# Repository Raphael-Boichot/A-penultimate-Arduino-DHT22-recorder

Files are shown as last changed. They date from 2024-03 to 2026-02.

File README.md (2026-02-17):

# Yet another Arduino DHT22 recorder on SD card (but with RTC)

## Why ?
Because I was not satisfied by other similar projects for my particular need: recording temperature and humidity every minute for very long periods of time (typically weeks) in remote parts of buildings. This device is so intended to be lost somewhere and survive power failures without much consequences on data stored. I've used it for recording two consecutive weeks of temperature and humidity without touching it, it worked. Current draw is very minimal and it can run for days on a powerbank. The whole price with 5 custom PCBs included should stay below 20€ shipped to your door direct through the silky road.

## How to use it ?
- Install the [Arduino IDE](https://www.arduino.cc/en/software), the [Adafruit sensor library](https://github.com/adafruit/Adafruit_Sensor), the [Adafruit DHT library](https://github.com/adafruit/DHT-sensor-library), the [U8g2 library for monochrome displays](https://github.com/olikraus/u8g2) and the [Adafruit RTClib library](https://github.com/adafruit/RTClib) from the IDE library manager;
- Flash the [DHT22_SD_Set_RTC.ino](Codes/DHT22_SD_Set_RTC/DHT22_SD_Set_RTC.ino) code to the device, it will set the date/time of the RTC module from the computer. The green LED stays ON if everything is OK. The serial must be set at 115200 bauds to check the output from Arduino IDE;
- Then flash the [DHT22_SD_Recorder.ino](Codes/DHT22_SD_Recorder/DHT22_SD_Recorder.ino) code. It immediately starts recording. You can follow what happens on the Arduino IDE serial or use [Read_from_Serial.m](Matlab_Stuff/Read_from_Serial.m) to plot temperature and humidity in live from Matlab;
- As long as green LED flashes only, everything is OK with the 3 modules. Any failure of one of them and the red LED flashes instead;
- SD card can be removed at any time to plot data, the device does not care, no need to power cycle it to plug the SD card back;
- When finished, data can be plotted from the SD card with [Read_from_txt_file.m](Matlab_Stuff/Read_from_txt_file.m), the Matlab code provided, but any other code would work as the data format is very simple;

Codes provided to extract data may be easily adapted to GNU Octave or Scilab.
 
## Parts needed
- An [Arduino Uno](https://fr.aliexpress.com/item/1005006088733150.html), the cheaper the better;
- A [generic microSD shield](https://fr.aliexpress.com/item/1005006059963950.html) or any other size if you do not use the custom PCB provided;
- A [DHT22 module with everything integrated](https://fr.aliexpress.com/item/1005005996195284.html). The red AM2302 stuff is the one I used;
- A [DS3231 RTC module](https://fr.aliexpress.com/item/1005005973972157.html). The extra chip on this board is just an independant 4kB flash chip that is not in use in this application (no idea what's the purpose in fact). It is recommended to [remove the resistor like in this image](Pictures/Resistor_to_remove.png) used for the janky charging circuit as the backup battery is not meant to be charged in fact;
- Some [male pin headers](https://fr.aliexpress.com/item/1005006104110168.html). The clearance with the Arduino Uno shield is tight, but triming the pins below the PCB is enough to go with regular 11 mm pin headers for the short board. The long one requires 15 mm pins headers at least;
- If you want to make the board entirely dismountable, use some [female regular pin headers](https://fr.aliexpress.com/item/1005006468451122.html) to connect the SD, RTC and DHT22 modules instead of soldering them directly;
- A [Custom PCB](https://github.com/Raphael-Boichot/A-penultimate-Arduino-DHT22-recorder/tree/main/PCB) if you want to stay on the neat side. Order at [JLCPCB](https://jlcpcb.com/), it's cheap and custom clean for Eu citizens contrary to PCBWay or OSHPark;
- 2 [regular 5 mm LEDs](https://fr.aliexpress.com/item/32848810276.html) (red and green) and two [through hole resistors](https://fr.aliexpress.com/item/32866216363.html) of about 220 Ohms (low value = high brighness).
- In option, you can daisy chain an i2C display with the RTC module, for example this [0.96 inch SSD1306 128x64 pixels OLED](https://aliexpress.com/item/1005007389730469.html).

To what I understand, pinout for SD card must be strict on Arduino and only Chip Select pin (CS) can be moved, so refer to the pinout given in the project. If you use an SD shield with included prototyping board, CS may differ (it's generally 4, 6 or 10 by default and sometimes even not indicated on the board...).

My own experience is that the backup battery has to be considered relevant for short accidental power loss only. The DS3231 RTC module is very seriously drifting if powered by its battery only (something like **90 minutes per day** with a fresh battery !). **It is meant to be continuously powered by VCC pin to keep on time**, which is written nowhere...
  
## The pinout (yes I like Powerpoint)
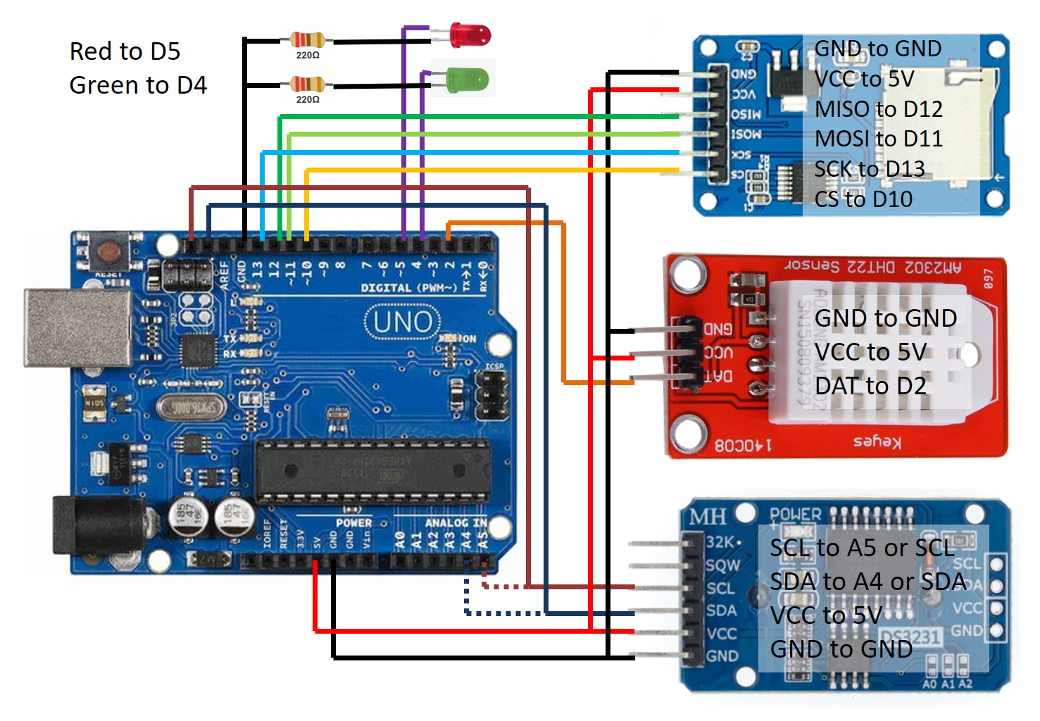
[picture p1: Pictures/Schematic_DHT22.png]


## Daisy chaining a 128x64 I2C display
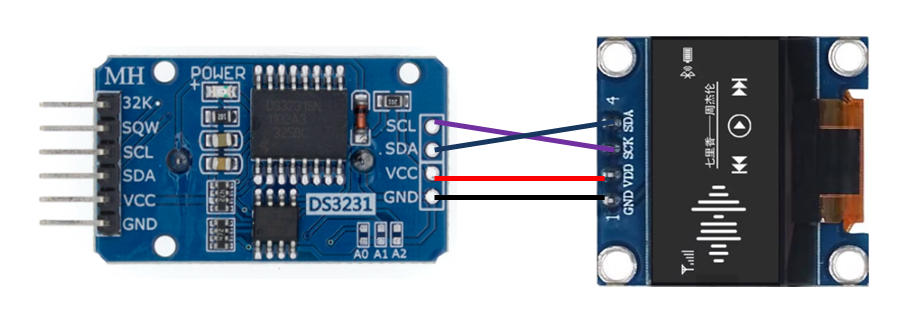
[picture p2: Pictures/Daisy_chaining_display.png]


## The PCBs that come with the project (Two flavors, long and short)
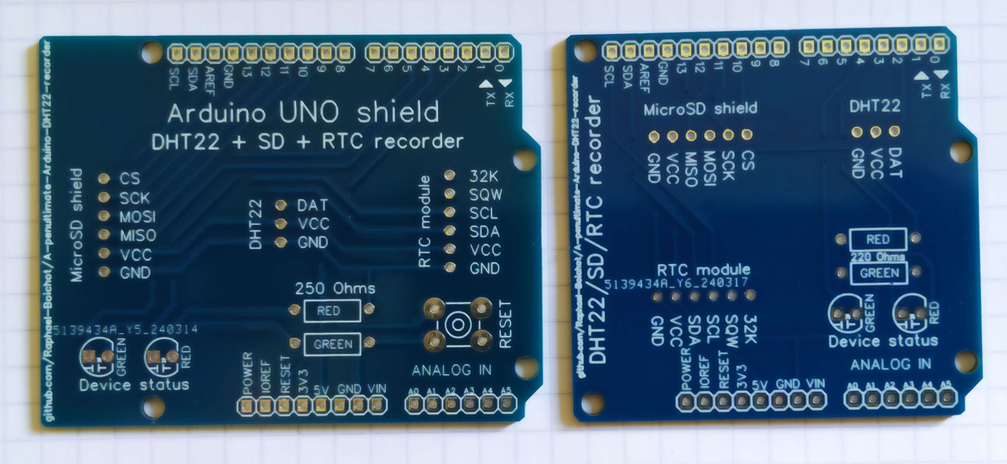
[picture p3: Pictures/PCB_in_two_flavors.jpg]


## The device as you will get it (short PCB)
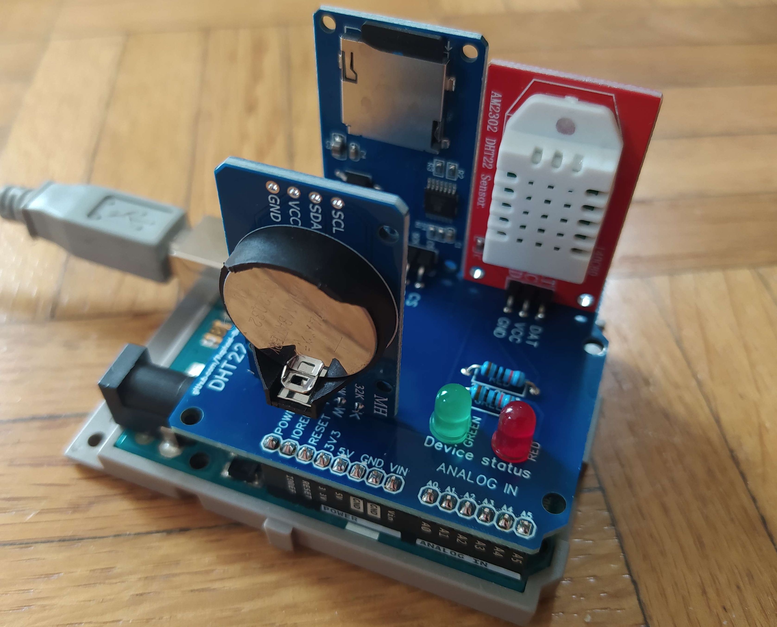
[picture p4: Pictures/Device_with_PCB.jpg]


## Janky version with display (but you get the idea)
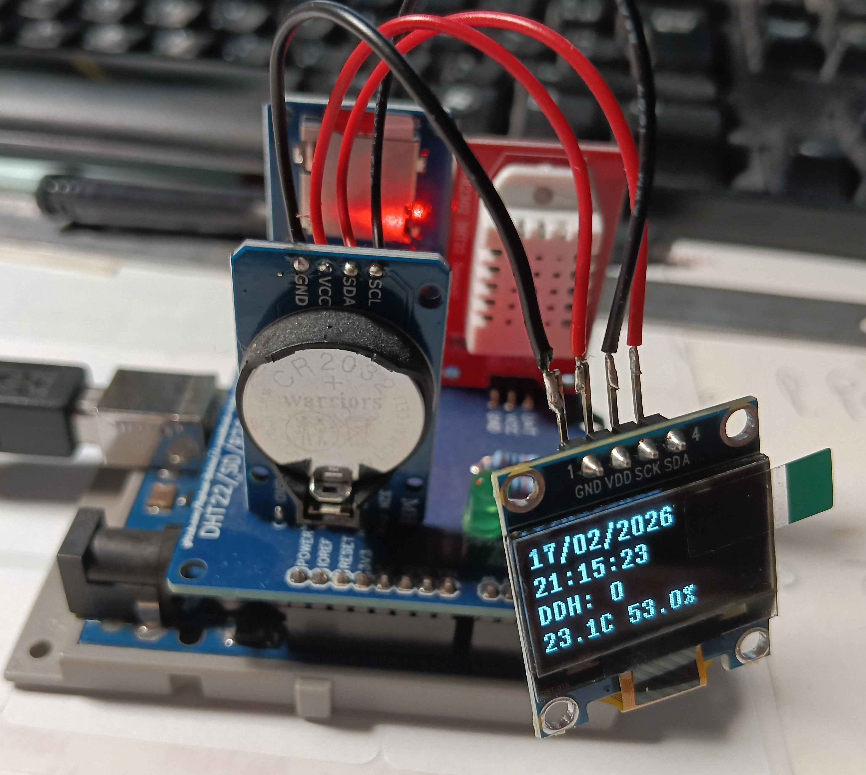
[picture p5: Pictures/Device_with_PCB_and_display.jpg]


## Protective shell to be used with the long PCB
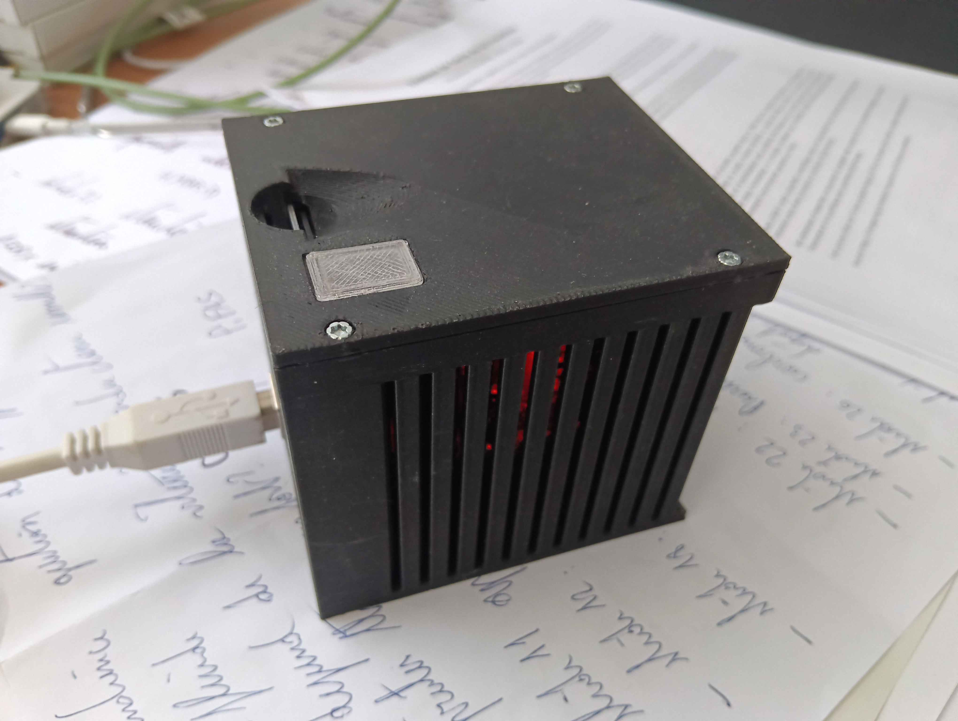
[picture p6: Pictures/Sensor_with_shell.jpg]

Device is here secretly recording temperature.

Each PCB comes with its json sources that can be edited with [EasyEDA std Edition](https://easyeda.com/page/download) if you want to customize it. It comes very pretty in blue I think. Two models of PCB are proposed: a short that do not hide the RESET button and a long with a deported RESET button. They both work the same. **The 3D shell is designed for the long version only.**

## Example of plot output vs time
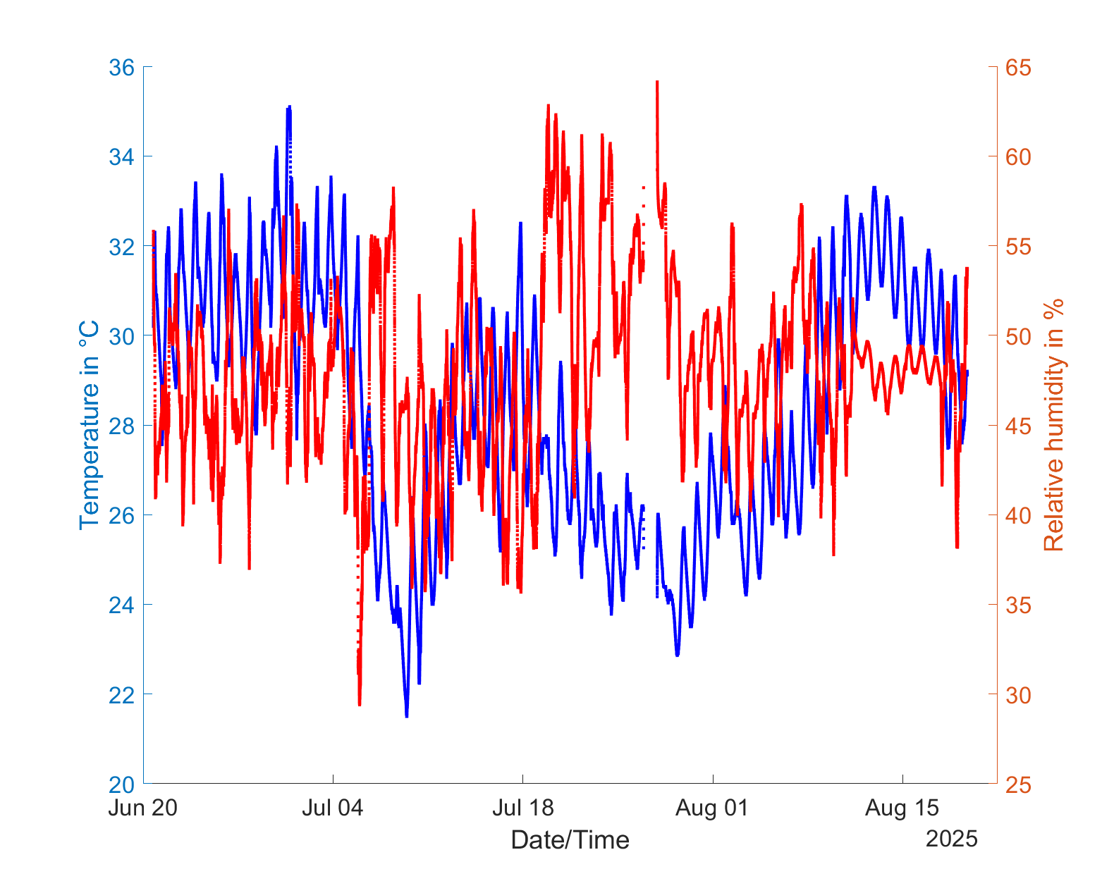
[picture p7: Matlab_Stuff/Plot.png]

This series of data has been recorded in an attic during 2 months. Data are treated with a 10 minutes moving average.

## Example of plot output in a psychrometric chart
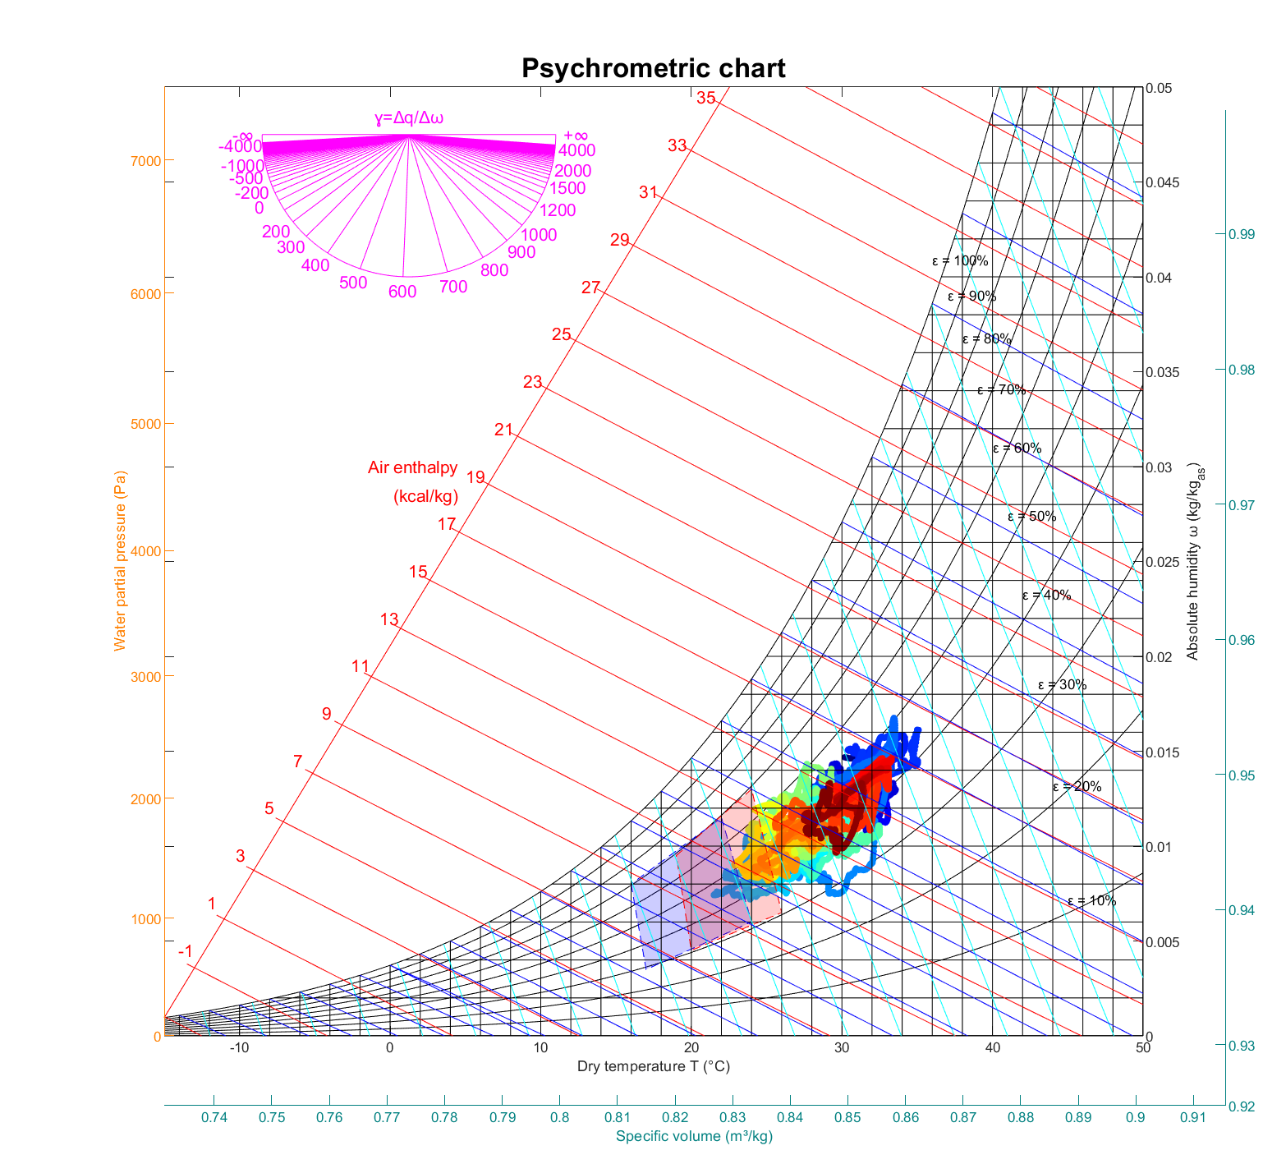
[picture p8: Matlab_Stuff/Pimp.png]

Same data than the preceding plot but presented differently. Data are treated with a 10 minutes moving average.

## Funfact
This device proved that the energy saving closure of a certain French university during two consecutive winters was only a political display since the heating remained on full blast during the entire closure. Thanks to this crap device I made new friends !

## Aknowledgements
The author wants to thank Pierre Chautard, Eva Azogui, Jingxiang Cao and Daniele Palladino from Phelma School of Engineering, Grenoble INP, France, for the psychrometric chart module.

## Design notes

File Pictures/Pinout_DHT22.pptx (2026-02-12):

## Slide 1

Red to D5
Green to D4

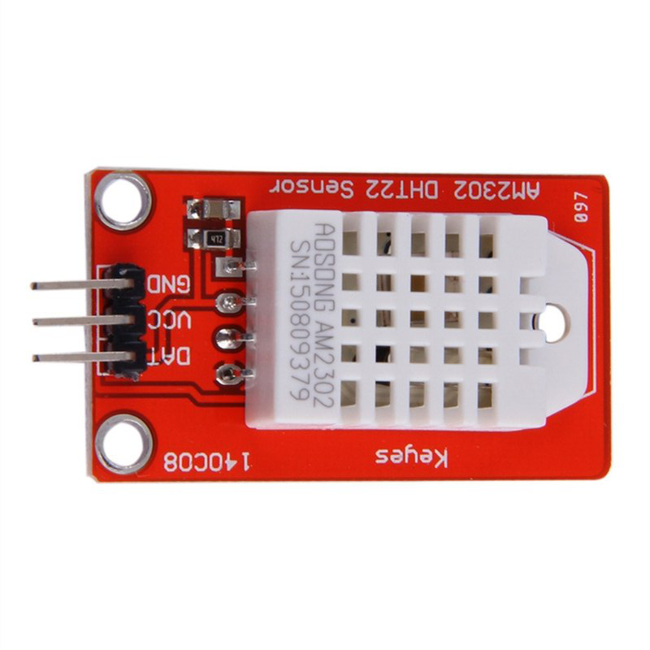
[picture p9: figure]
AM2302 DHT22 Module numérique de température et d'humidité de capacité
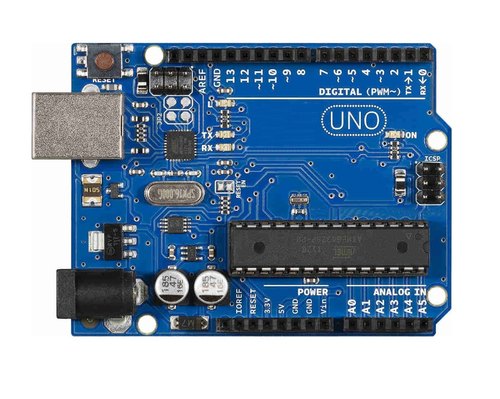
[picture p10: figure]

GND to GND
VCC to 5V
DAT to D2

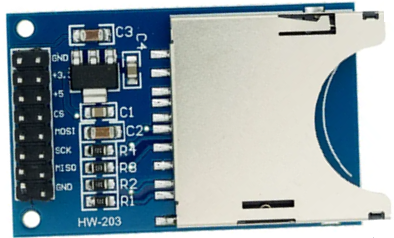
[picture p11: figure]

CS to D10
MOSI to D11
MISO to D12
SCK to D13
GND to GND
+5 to 5V

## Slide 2

+5 to 5V
CS to D10
MOSI to D11
SCK to D13
MISO to D12
GND to GND

Red to D5
Green to D4

GND to GND
VCC to 5V
DAT to D2

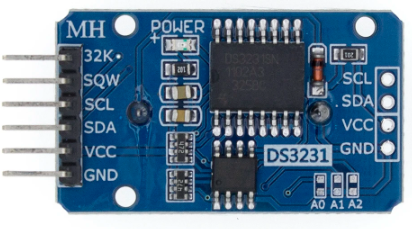
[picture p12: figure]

SCL to A5
SDA to A4
VCC to 5V
GND to GND

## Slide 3

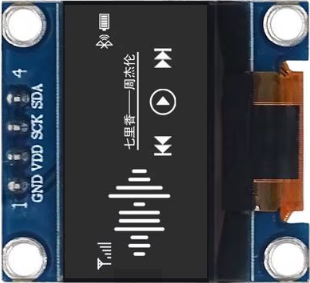
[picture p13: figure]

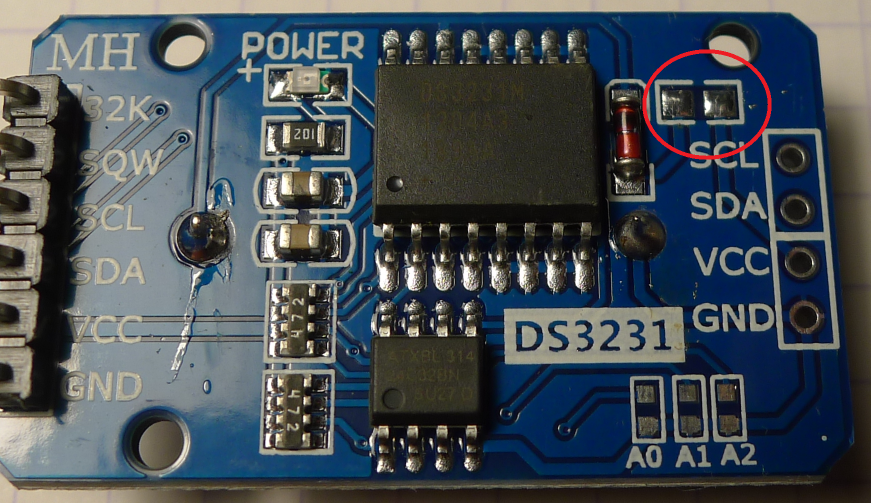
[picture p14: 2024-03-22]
Pictures/Resistor_to_remove.png

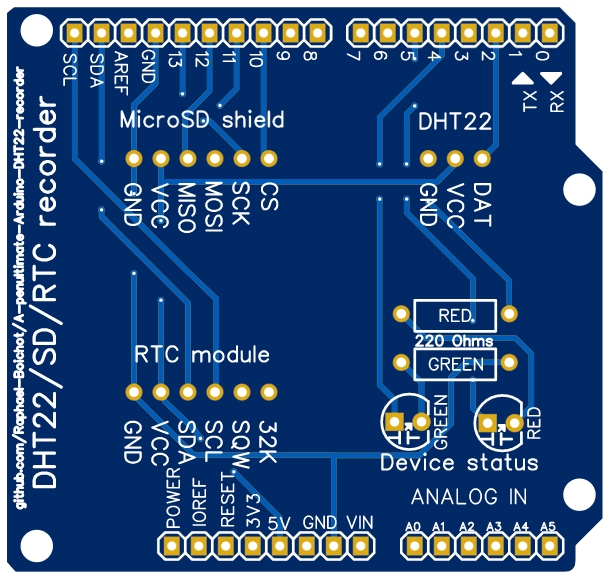
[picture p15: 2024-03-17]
PCB/Short/PCB.png

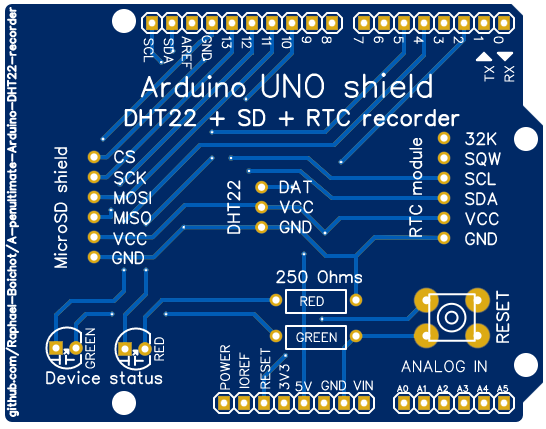
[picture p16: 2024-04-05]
PCB/Long/PCB.png

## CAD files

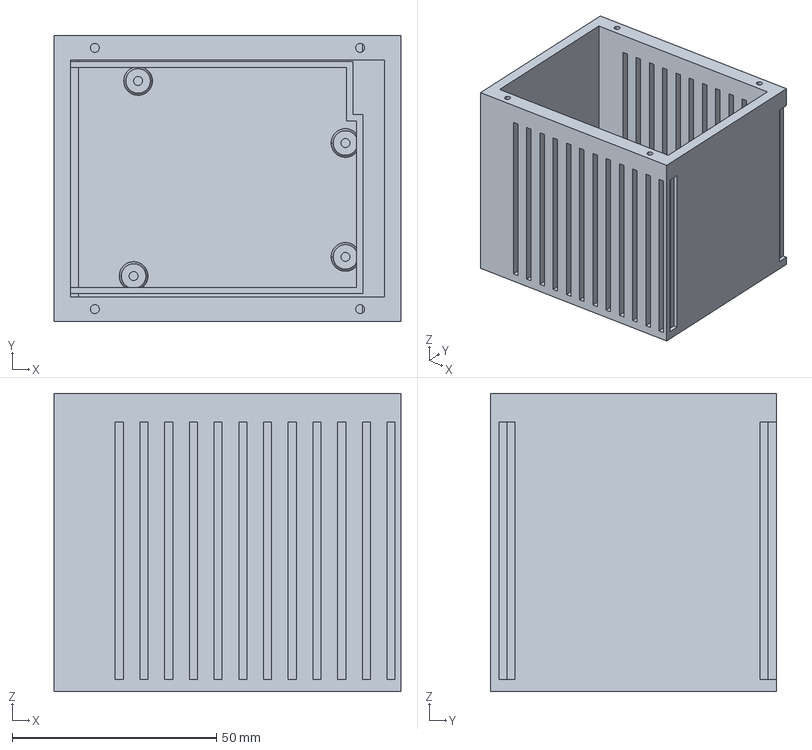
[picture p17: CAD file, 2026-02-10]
Shell_step_files/Main_shell.stp
85.0 x 70.0 x 73.0 mm

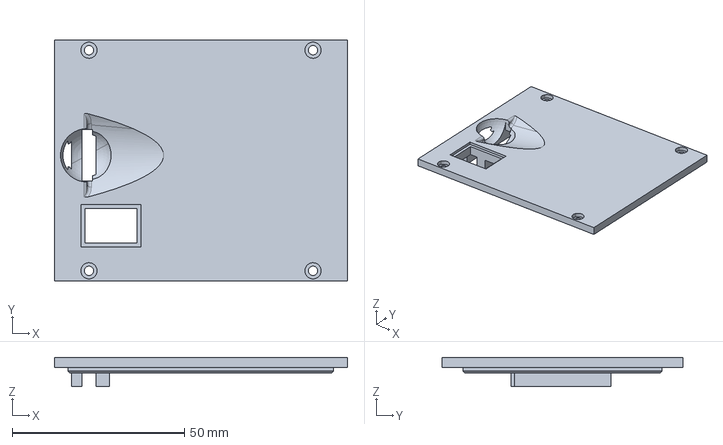
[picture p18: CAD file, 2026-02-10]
Shell_step_files/Lid_with_SD_notch.stp
85.0 x 70.0 x 8.50 mm

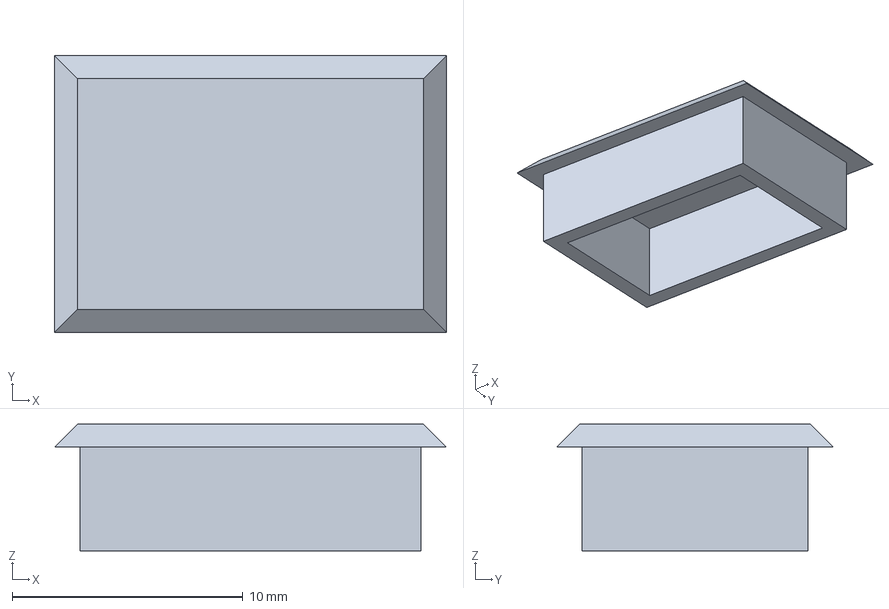
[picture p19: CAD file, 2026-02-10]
Shell_step_files/Little_transparent_window.stp
17.0 x 12.0 x 5.50 mm

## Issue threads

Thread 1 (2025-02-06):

librairie manquante I2C adafruit

brunoMal, 2025-02-06:
Bonjour
il faut aussi installer cette librairie : https://github.com/adafruit/Adafruit_Sensor

A+

Raphael-Boichot, 2025-02-06:
C'est corrigé, merci Bruno !

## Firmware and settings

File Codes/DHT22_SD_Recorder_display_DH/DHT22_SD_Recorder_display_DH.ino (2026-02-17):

/*
  Code adapted initially from here by Raphaël BOICHOT, january 2023, use at your own risk
  https://microcontrollerslab.com/dht22-data-logger-arduino-micro-sd-card/
  to be used with the following libraries:
  https://github.com/adafruit/DHT-sensor-library
  https://github.com/adafruit/RTClib
  https://github.com/olikraus/u8g2 (this tiny library is the only possible due to Arduino memory limitation)
  128x64 pixels OLED daisy chained to the RTC module (see readme.md schematic)
------------------------------------------------------------------------------------------------------
  pinout Arduino to SD   |  Arduino to DHT22   |    Arduino to LEDS        |   Arduino to RTC (DS3231)
  GND<->GND              |  GND<->GND          |    GND<->led cathodes     |   A4 or SDA<->SCL
  +5V<->+5V              |  +5V<->VCC          |    D4<->green led anode   |   A5 or SCL<->SDA
  D10<->CS               |  D2<->DAT           |    D5<->red led anode     |   GND<->GND
  D11<->MOSI             |                     |                           |   +5V<->VCC
  D12<->MISO             |                     |                           |   SQW not connected
  D13<->SCK              |                     |                           |   32K not connected
-------------------------------------------------------------------------------------------------------
 */
#include "SD.h"
#include <SPI.h>
#include "DHT.h"
#include <Wire.h>
#include <RTClib.h>
#include <U8x8lib.h>  // Added for OLED

// OLED Initialization
U8X8_SSD1306_128X64_NONAME_HW_I2C u8x8(/* reset=*/U8X8_PIN_NONE);

RTC_DS3231 rtc;
#define DHTPIN 2
#define DHTTYPE DHT22
DHT dht(DHTPIN, DHTTYPE);
File myFile;

// --- GLOBAL VARIABLES FOR DH CALCULATION ---
float tempSum = 0;             // Sum of temperatures for the current hour
int sampleCount = 0;           // Number of readings taken in the current hour
float discomfortdegreeHours = 0;         // Cumulative Degree Hours (DH)
int lastHour = -1;             // To detect when a new hour starts
const float THRESHOLD = 28.0;  // 28°C threshold, from French RE2020
// https://www.ffbatiment.fr/techniques-batiment/reglementation-construction/reglementation-thermique-environnementale/dossier/re2020-confort-d-ete-et-indicateur-dh
// set of variables for calculating the degre.hour
// Guideline: <350 degre.hours per year, building OK, >1250 degre.hours per year, building NG

int RED_LED = 5;
int GREEN_LED = 4;
int CHIP_SELECT = 10;
unsigned long delay_s = 60;
unsigned long preceding_time, preceding_timeLED, preceding_timeDisplay;
int def_LED;
String Temperature, Humidity, Data;
bool sd_ok = false;
bool rtc_ok = false;

void setup() {
  pinMode(RED_LED, OUTPUT);
  pinMode(GREEN_LED, OUTPUT);
  Serial.begin(115200);
  while (!Serial)
    ;

  // ORIGINAL SERIAL MESSAGES
  Serial.println(F("// By Raphaël BOICHOT, March 2024"));
  Serial.println(F("// This program comes with ABSOLUTELY NO WARRANTY;"));
  Serial.println(F("// This is free software, and you are welcome to redistribute it"));

  // OLED Setup
  u8x8.begin();
  u8x8.setPowerSave(0);
  u8x8.setFont(u8x8_font_7x14B_1x2_f);  // Set to Big Bold Font

  digitalWrite(RED_LED, 1);
  digitalWrite(GREEN_LED, 1);
  delay(2500);
  digitalWrite(RED_LED, 0);
  digitalWrite(GREEN_LED, 0);

  def_LED = GREEN_LED;
  Serial.println(F("// Initializing DHT22 sensor..."));
  dht.begin();
  if (isnan(dht.readTemperature()) || isnan(dht.readHumidity())) {
    Serial.println(F("// DHT22 Sensor not working !"));
    def_LED = RED_LED;
  }

  Serial.println(F("// Initializing SD card..."));
  sd_ok = SD.begin(CHIP_SELECT);
  if (!sd_ok) {
    Serial.println(F("// SD initialization failed !"));
    def_LED = RED_LED;
  } else {
    Serial.println(F("// SD initialization OK !"));
    Data = F("The device has restarted following a power cut");
    myFile = SD.open("data.txt", FILE_WRITE);
    Serial.println(F("// Writing power down marker to data.txt..."));
    myFile.println(Data);
    myFile.close();
  }

  Serial.println(F("// Initializing RTC module..."));
  rtc_ok = rtc.begin();
  if (!rtc_ok) {
    Serial.println(F("// RTC module not responding !"));
    def_LED = RED_LED;
  }

  for (int j = 0; j < 10; j++) {
    digitalWrite(def_LED, 1);
    delay(20);
    digitalWrite(def_LED, 0);
    delay(100);
  }

  preceding_time = millis();
  preceding_timeLED = millis();
  preceding_timeDisplay = millis();
  Serial.println(F("// Starting recording..."));
}

void loop() {
  // INDICATE DEVICE IS RUNNING & UPDATE OLED
  if ((millis() - preceding_timeLED) >= (1000)) {
    preceding_timeLED = millis();
    digitalWrite(def_LED, 1);
    delay(10);
    digitalWrite(def_LED, 0);
    updateOLED();  // Refresh the screen every second
  }

  if ((millis() - preceding_time) >= (delay_s * 1000)) {
    preceding_time = millis();
    if (isnan(dht.readTemperature()) || isnan(dht.readHumidity())) {
      Serial.println(F("// DHT22 Sensor not working !"));
      def_LED = RED_LED;
    } else {
      data_logging();
    }
  }
}

void updateOLED() {
  DateTime now = rtc.now();
  
  // Row 0: Date
  u8x8.setCursor(0, 0);
  if (now.day() < 10) u8x8.print('0'); u8x8.print(now.day()); u8x8.print('/');
  if (now.month() < 10) u8x8.print('0'); u8x8.print(now.month()); u8x8.print('/');
  u8x8.print(now.year());

  // Row 2: Time + Blinking SD Alert
  u8x8.setCursor(0, 2);
  if (now.hour() < 10) u8x8.print('0'); u8x8.print(now.hour()); u8x8.print(':');
  if (now.minute() < 10) u8x8.print('0'); u8x8.print(now.minute()); u8x8.print(':');
  if (now.second() < 10) u8x8.print('0'); u8x8.print(now.second()); 
  
  if (!sd_ok) {
    if (now.second() % 2 == 0) u8x8.print(F("  [SD!]")); 
    else u8x8.print(F("       ")); 
  } else {
    u8x8.print(F("       "));
  }

  // Row 4: DDH Calculation
  u8x8.setCursor(0, 4);
  u8x8.print(F("DDH: "));
  u8x8.print(discomfortdegreeHours, 0);
  u8x8.print(F("   ")); 

  // Row 6: Temperature & Humidity
  u8x8.setCursor(0, 6);
  u8x8.print(dht.readTemperature(), 1);
  u8x8.print(F("C "));
  u8x8.print(dht.readHumidity(), 1);
  u8x8.print(F("%"));
}

void data_logging() {
  // 1. READ SENSORS
  float currentTemp = dht.readTemperature();
  float currentHum = dht.readHumidity();
  String Temperature = String(currentTemp, 2);
  String Humidity = String(currentHum, 2);

  // 2. RTC INITIALIZATION
  rtc_ok = rtc.begin();
  if (!rtc_ok) {
    Serial.println(F("// RTC module not responding !"));
    def_LED = RED_LED;
  }

  DateTime date = rtc.now();
  int currentHour = date.hour();

  // --- DEGREE HOURS (DH) LOGIC ---

  // Check if a new hour has started to finalize the previous hour's average
  if (lastHour != -1 && currentHour != lastHour) {
    if (sampleCount > 0) {
      float averageTemp = tempSum / sampleCount;
      // If average is above threshold, add the difference to DH
      if (averageTemp > THRESHOLD) {
        discomfortdegreeHours += (averageTemp - THRESHOLD);
      }
    }
    // Reset counters for the new hour
    tempSum = 0;
    sampleCount = 0;
  }

  // Accumulate data for the current hour
  tempSum += currentTemp;
  sampleCount++;
  lastHour = currentHour;

  // 3. FORMAT DATA STRING
  char formattedDate[20];
  sprintf(formattedDate, "%04d-%02d-%02d %02d:%02d:%02d",
          date.year(), date.month(), date.day(),
          date.hour(), date.minute(), date.second());

  // Create the final data string including DH
  Data = "Temperature: " + Temperature + " Humidity: " + Humidity + " Date/Time: ";
  Data = Data + formattedDate + " | DH: " + String(discomfortdegreeHours, 2);


  Serial.println(Data);

  // 4. SD CARD LOGGING
  sd_ok = SD.begin(CHIP_SELECT);
  if (!sd_ok) {
    Serial.println(F("// Writing failed, card not connected !"));
    def_LED = RED_LED;
    digitalWrite(def_LED, HIGH);
    delay(200);
    digitalWrite(def_LED, LOW);
  } else {
    myFile = SD.open("data.txt", FILE_WRITE);
    def_LED = GREEN_LED;
    digitalWrite(def_LED, HIGH);
    delay(200);
    digitalWrite(def_LED, LOW);
    myFile.println(Data);
    myFile.close();
  }
}

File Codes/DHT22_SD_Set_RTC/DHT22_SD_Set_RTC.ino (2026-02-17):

#include <Wire.h>
#include <RTClib.h>  //https://github.com/adafruit/RTClib

RTC_DS3231 rtc;
int RED_LED = 5;
int GREEN_LED = 4;

void setup() {
  Serial.begin(115200);
  pinMode(RED_LED, OUTPUT);
  pinMode(GREEN_LED, OUTPUT);

  if (!rtc.begin()) {
    digitalWrite(RED_LED, 1);
    Serial.println(F("// RTC Module not working !"));
    while (1)
      ;
  }

  // 1. Capture the "New Time" (Compilation time)
  DateTime pcTime = DateTime(__DATE__, __TIME__);

  // 2. Capture the "Current RTC Time" (Before sync)
  DateTime rtcTime = rtc.now();

  // 3. Calculate Drift
  // unixtime() gives total seconds since Jan 1st 1970
  long driftSeconds = pcTime.unixtime() - rtcTime.unixtime();

  Serial.println(F("--- RTC SYNC REPORT ---"));
  Serial.print(F("RTC Time: "));
  Serial.println(rtcTime.timestamp());
  Serial.print(F("PC Time:  "));
  Serial.println(pcTime.timestamp());

  Serial.print(F("Drift detected: "));
  Serial.print(driftSeconds);
  Serial.println(F(" seconds"));

  if (abs(driftSeconds) > 2) {
    Serial.println(F("// Drift > 2s: Injecting PC time..."));
    rtc.adjust(pcTime);
    digitalWrite(GREEN_LED, 1);
    delay(1000);
    digitalWrite(GREEN_LED, 0);
  } else {
    Serial.println(F("// Time is already accurate. No sync needed."));
  }
  Serial.println(F("-----------------------"));
}

void loop() {
  DateTime date = rtc.now();
  // this part was made with ChatGPT
  char formattedDate[20];  // Table to store the formatted date
  // Date format YYYY-MM-DD HH:MM:SS
  sprintf(formattedDate, "Date/Time: %04d-%02d-%02d %02d:%02d:%02d", date.year(), date.month(), date.day(), date.hour(), date.minute(), date.second());
  // end of part made with ChatGPT
  Serial.println(formattedDate);
  delay(1000);
}

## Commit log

2026-02-10 Update README with temperature recording note
    Added note about device secretly recording temperature.
2026-02-12 Revise README with updated usage instructions and components
    Updated instructions for using the device and clarified component details.
